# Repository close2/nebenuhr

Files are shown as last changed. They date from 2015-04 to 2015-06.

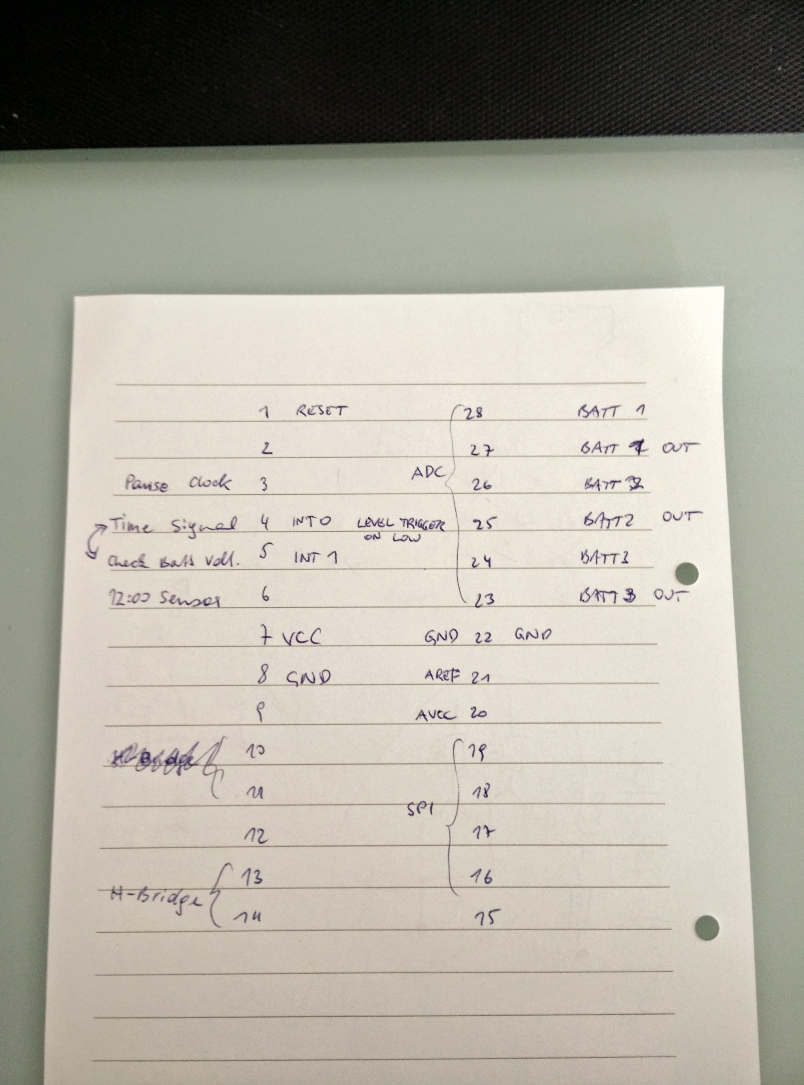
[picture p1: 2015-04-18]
doc/IMG_20150418_123037.jpg

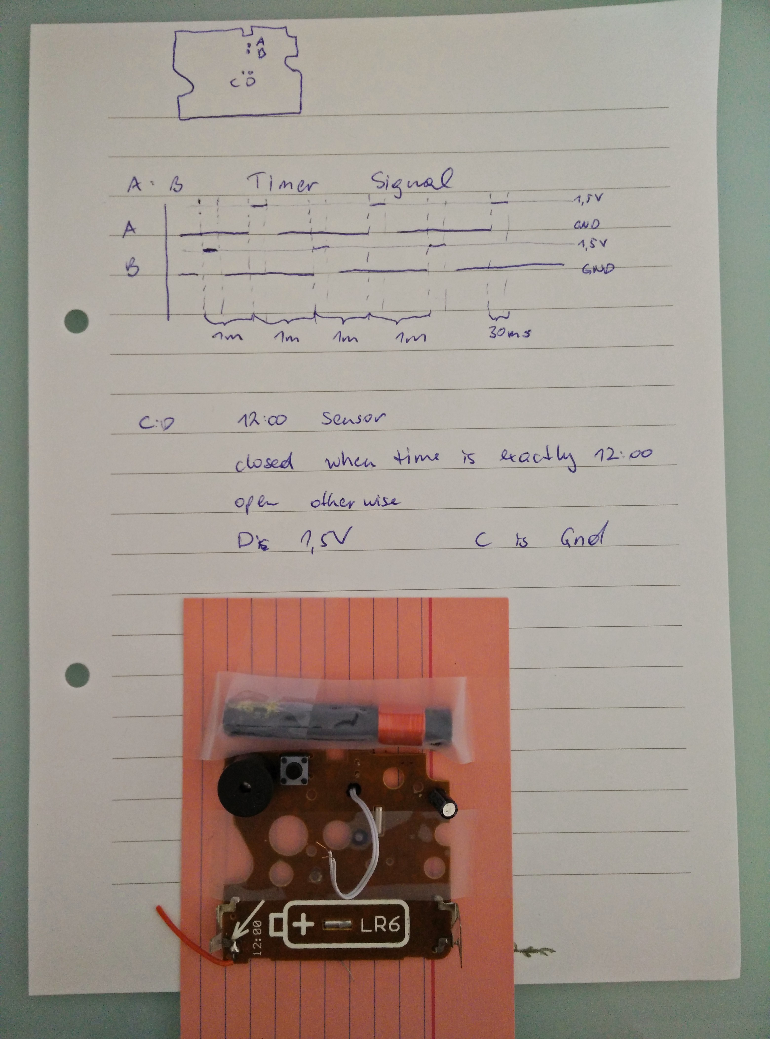
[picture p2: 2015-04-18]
doc/IMG_20150418_123128.jpg

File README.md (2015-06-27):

# nebenuhr
atmega code to control a secondary clock which would normally get its signal from a master clock.

## Idea

I reuse the board of a broken radio controlled clock.

See images in the doc directory.

The pins A and B of the clock powered a coil for a short amount of time (30ms) every minute.
As you can see in the diagram the polarity is reversed every minute.  (This is exactly the same
for the Nebenuhr.)  The signal on pins A and B are called timeSignal in my code.

When both arms (minute and hour) were at 12 o'clock Pin D was connected to ground (Pin C).

In my code I call this the noonSensor.  This was originally done with a light-sensor and 2 holes
in the hour/minute arms.

An Atmega is connected to the 3 (A, B and D) relevant pins of this board.

## Atmega

In order to use as little power as possible we power down the Atmega between timerSignals.

Only a low can wake an atmega when powered off,

                           VCC
                            |
                            1MΩ
                            |
                            ----------- Atmega TimeSignal Pin (INT1)
                            /
     Pin A -- 1MΩ -- Base |<
                            ↘
                             |
                            GND

And again the same for B.  Note that both A and B finally connect to the same Atmega pin.
(One resistor to VCC would be enough).

When A goes high (1.5V) the transistor pulls the Atmega pin to ground, waking the Atmega.

I considered connecting Pin D directly to the atmega and switching between HiZ and low,
but decided to play it safe.  A Mosfet connects Pin D to ground, when an Atmega pin
goes high:

    Pin D --
           |
           | Drain
           |
           Mosfet  Gate ---- 1kΩ ----- Atmega NoonSignal Pin
           |
           | Source
           |
          GND

An HBridge will power the coils of the nebenuhr.

                                 VCC
                                  |
                                  1MΩ
                                  |
       to P Channel left side  ----
                                   \
                                    >| 1kΩ -- Atmega HBridge1 Pin
                                   ↙        |
                                  |         |
                                 500kΩ     1kΩ
                                  |         |
                                 GND        to N Channel right side

Similar for P Channel right side, N Channel left side and HBridge2 Pin.

## Pause pin

Because the clock is pretty loud, setting a pin high disables the h-bridge output.
The atmega keeps count of the missed minute-arm movements and outputs them when the pin is set
low again.

The pin is simply either connected to VCC or GND:

              VCC
               |
                \
    
                     -- 1MΩ -- Atmega Pause Pin
    
                /
               |
              GND

## Battery check

As we have 3 power sources now:
* 1 AA battery for the old rc clock
* 1 battery (4.5V?) for the atmega
* 3 4.5V in series for the H-Bridge

i wanted to make it easy for the owner of the clock to find out, why the clock stopped working.
Pushing a button (INT0) will compare those voltages (or rather the divided voltages) to 1.1V and
turn on corresponding LEDs if the voltage seems high enough.

This was by far the most work.  *Don't do it.*

Either really remove the code, or connect 1MΩ to VCC on the check battery pin.

The difficulties:

- the voltage divider for the voltages should only be powered when the button is pressed.  
  I added Mosfets to only connect the voltage dividers to ground during measurements.
- the HBridge/ Nebenuhr voltage is to high for the atmega → simply not connecting to GND
  would result in 15+V to one of the atmega pins.  I finally simply added an solid state
  relay.
- Pressing the check battery button should wake the atmega and the button therefore connects
  the atmega pin to GND when pressed.  
  This means that I can not use the button to power the voltage divider. To measure the
  atmega voltage I used another pin to power the atmega voltage divider.

## libcl

This project uses my still incomplete libcl library.
Hopefully I will complete this libary soon and remove the header files from this project.
(And reference my libcl repository instead).

# Usage

- Power the atmega 4.5V
- Power the Nebenuhr ~15V
- move the Nebenuhr arms to 2 minutes before 12:00
- Power the rc-clock.

The rc-clock will now send 2 timer signals until the atmega sends the noon-signal.

Then the rc-clock will wait for an rc-signal.  In my case this could take several hours.

# Feel free to contact me.

I have the impression that writing this documentation costs me far more time than simply
answering questions... :(

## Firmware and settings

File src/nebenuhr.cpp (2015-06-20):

#define F_CPU 1000000UL

#include <avr/sleep.h>
#include "macros.h"
#include "tasks.h"
#include "clock.h"
#include "irqs.h"
#include "adc.h"


// wait timeSignalWaitPeriod ms until timeSignal is no longer present
// before turning IRQ for timeSignal on again.
const uint16_t timeSignalWaitPeriod = 10;

// when displayed time is not time, we move the minute finger faster
// but we will wait this pause (in ms) between every finger movement.
const uint16_t pauseBetweenHBridgePulses = 250;


template <typename T>
constexpr uint8_t voltsToUnits(T volts) {
  return 256 * volts / 1.1;
}

// 256 * minBatt1Voltage / 1.1 (1.1 ref voltage)
const auto batt1Min = voltsToUnits(0.8); // should be 186 units
const auto batt2Min = voltsToUnits(0.6);
const auto batt3Min = voltsToUnits(0.8); // should be 186 units


typedef PIN_DIP_3 PauseClockPin;

// DIP_4 is INT1 irq
typedef PIN_DIP_4 CheckBatteryVoltagePin;

// DIP_5 is INT0 irq
typedef PIN_DIP_5 TimeSignalPin;

typedef PIN_DIP_6 NoonSensorPin;


typedef PIN_DIP_13 HBridge1;
typedef PIN_DIP_14 HBridge2;

typedef PIN_DIP_11 VoltageFetPin;
typedef PIN_DIP_28 Batt1Pin;
typedef PIN_DIP_27 Batt1OutPin;
typedef PIN_DIP_26 Batt2Pin;
typedef PIN_DIP_25 Batt2OutPin;
typedef PIN_DIP_24 Batt3Pin;
typedef PIN_DIP_23 Batt3OutPin;


// using jumpers on the following pins let the user switch between different
// timings
typedef PIN_DIP_15 DurationIn0;
typedef PIN_DIP_16 DurationIn1;
typedef PIN_DIP_17 DurationIn2;
typedef PIN_DIP_18 DurationIn3;
typedef PIN_DIP_19 DurationIn4;

const uint16_t durations[32] = {
  ms_to_units((uint16_t) 130), // 0
  ms_to_units((uint16_t) 140),
  ms_to_units((uint16_t) 150),
  ms_to_units((uint16_t) 160),
  ms_to_units((uint16_t) 170),
  ms_to_units((uint16_t) 180),
  ms_to_units((uint16_t) 190),
  ms_to_units((uint16_t) 200),
  ms_to_units((uint16_t) 210),
  ms_to_units((uint16_t) 220),
  ms_to_units((uint16_t) 230), // 10
  ms_to_units((uint16_t) 240),
  ms_to_units((uint16_t) 250),
  ms_to_units((uint16_t) 260),
  ms_to_units((uint16_t) 270),
  ms_to_units((uint16_t) 280),
  ms_to_units((uint16_t) 290),
  ms_to_units((uint16_t) 300),
  ms_to_units((uint16_t) 320),
  ms_to_units((uint16_t) 340),
  ms_to_units((uint16_t) 360), // 20
  ms_to_units((uint16_t) 380),
  ms_to_units((uint16_t) 400),
  ms_to_units((uint16_t) 420),
  ms_to_units((uint16_t) 440),
  ms_to_units((uint16_t) 460),
  ms_to_units((uint16_t) 480),
  ms_to_units((uint16_t) 500),
  ms_to_units((uint16_t) 525),
  ms_to_units((uint16_t) 550),
  ms_to_units((uint16_t) 600), // 30
  ms_to_units((uint16_t) 650)
};

uint16_t time; // in minutes from 12:00; wraps every 12*60 minutes

// we allow the displayed time to be pause (for instance during the night,
// because the clock is really loud)
uint16_t displayedTime; // in minutes from 12:00; wraps every 12*60 minutes


///////////////////////////////  Task managment  ///////////////////////////////

enum Task {
  IncMinute = 0,
  CheckBatteries = 1,
  ReenableTimerSignalIrq = 2
};

uint8_t tasksToRun;


void startTask(Task task) {
  tasksToRun |= _BV(task);
}

void stopTask(Task task) {
  tasksToRun &= ~(_BV(task));
}

void stopAllTasks() {
  tasksToRun = 0;
}
  
uint8_t isAllTasksStopped() {
  return tasksToRun == 0;
}

uint8_t isTaskStarted(Task task) {
  return tasksToRun & _BV(task);
}
////////////////////////////////////////////////////////////////////////////////


////////////////////  NoonSensor -- related functionality  /////////////////////

void setNoonSensor(uint8_t v) {
  SET_BIT(NoonSensorPin, PORT, v);
}

void initNoonSensor() {
  SET_BIT(NoonSensorPin, DDR, 1);
  // do not automatically start with noon sensor on
}
////////////////////////////////////////////////////////////////////////////////


/////////////////  TimerSignal -- INT1 related functionality  //////////////////

void enableTimerSignalIRQ() {
  EIMSK |= _BV(INT1);
}

void disableTimerSignalIRQ() {
  EIMSK &= ~(_BV(INT1));
}

void initTimerSignal() {
  // nothing to do for pin
  // pins are Hi-Z input by default
  
  // turn on irq
  enableTimerSignalIRQ();
  sei();
}

#define NEW_IRQ_TASK IncMinuteIrqTask
IRQ_TASK(NEW_IRQ_TASK) {
  time++;
  if (time == 12 * 60) {
    time = 0;
    setNoonSensor(1);
  }
  else setNoonSensor(0);
        

  startTask(Task::IncMinute);
  startTask(Task::ReenableTimerSignalIrq);
  
  // turn off IRQ until signal from real clock is no longer present
  // otherwise this IRQ will trigger too often.
  disableTimerSignalIRQ();
};
#include "internal/register_irq_task_INT1.h"

uint8_t timerSignalPresent() {
  return GET_BIT(TimeSignalPin, PIN) == 0;
}

#define NEW_TASK ReenableTimerSignalIrqTask
struct NEW_TASK {
  static inline uint8_t is_enabled() {
    return isTaskStarted(Task::ReenableTimerSignalIrq);
  }
  
  template<typename T>
  static inline T run(const T& clock) {
    // we have to make sure the timeSignal is no longer present, before
    // turning irq for timeSignal on again.
    if (!timerSignalPresent()) {
      stopTask(Task::ReenableTimerSignalIrq);
      enableTimerSignalIRQ();
      return 0;
    }
    return ms_to_units(timeSignalWaitPeriod);
  }
};
#include REGISTER_TASK
////////////////////////////////////////////////////////////////////////////////


/////////////////  CheckBattery -- INT0 related functionality  /////////////////

void enableCheckBatteryIRQ() {
  EIMSK |= _BV(INT0);
}

void disableCheckBatteryIRQ() {
  EIMSK &= ~(_BV(INT0));
}

void initCheckBatteryPin() {
  // nothing to do for input pin
  // pins are Hi-Z input by default
  
  // turn output pins to output:
  SET_BIT(Batt1OutPin, DDR, 1);
  SET_BIT(Batt2OutPin, DDR, 1);
  SET_BIT(Batt3OutPin, DDR, 1);
  
  SET_BIT(VoltageFetPin, DDR, 1);
  
  // turn on irq
  enableCheckBatteryIRQ();
  sei();
}

#define NEW_IRQ_TASK CheckBatteryIrqTask
IRQ_TASK(NEW_IRQ_TASK) {
  startTask(Task::CheckBatteries);
  
  // turn off IRQ until button is no longer pressed
  // otherwise this IRQ will trigger too often.
  disableCheckBatteryIRQ();
};
#include "internal/register_irq_task_INT0.h"

uint8_t checkBatteryPressed() {
  return GET_BIT(CheckBatteryVoltagePin, PIN) == 0;
}
////////////////////////////////////////////////////////////////////////////////


////////////////////  PauseClock -- related functionality  /////////////////////

void initClockPaused() {
  // nothing to do
  // pins are Hi-Z input by default
}

uint8_t clockPaused() {
  return GET_BIT(PauseClockPin, PIN);
}
////////////////////////////////////////////////////////////////////////////////



///////////////  HBridgeOutDuration -- related functionality  //////////////////

void initHBridge() {
  SET_BIT(HBridge1, DDR, 1);
  SET_BIT(HBridge2, DDR, 1);
}

uint16_t readHBridgeOutDuration_units() {
  uint8_t index;
  // pins are by default input
  index = GET8_BYTE(PIN, 0, PIN_UNUSED, PIN_UNUSED, PIN_UNUSED, DurationIn4, DurationIn3, DurationIn2, DurationIn1, DurationIn0);
  
  return durations[index];
}
////////////////////////////////////////////////////////////////////////////////


#define NEW_TASK IncMinuteTask
struct NEW_TASK {
  static inline uint8_t is_enabled() {
    return isTaskStarted(Task::IncMinute);
  }
  
  template<typename T>
  static inline T run(const T& clock) {
    // this task will be called twice for every minute increment.
    // first to turn the output on and second to turn it off again.
    
    // we also need to keep track if we have to send a positive or negative
    // signal.
    
    enum HBridgeState {
      On = 0,
      OffPause = 1,
      Off = 2
    };
    
    static HBridgeState hBridgeState = Off;
    
    const uint8_t clockP = clockPaused();
    
    const uint8_t bridgeSelector = displayedTime & 0b1;
    
    if (hBridgeState == Off) {
      
      hBridgeState = On;
      if (!clockP) {
        if (bridgeSelector == 0) SET_BIT(HBridge1, PORT, 1);
        else SET_BIT(HBridge2, PORT, 1);

        displayedTime++;
        if (displayedTime == 12 * 60) displayedTime = 0;
      }
      
      // sleep for hbridgeOutDuration
      return readHBridgeOutDuration_units();
    } else if (hBridgeState == On) {
      
      hBridgeState = OffPause;
    
      // state is on → turn off
      SET_BIT(HBridge1, PORT, 0);
      SET_BIT(HBridge2, PORT, 0);
      
      return ms_to_units(pauseBetweenHBridgePulses);
    } else { // HBridgeState == OffPause
      
      hBridgeState = Off;
      
      if (clockP || displayedTime == time) {
        // mark IncMinuteTask as done:
        //             disable task in tasktracker
        stopTask(Task::IncMinute);
      }
    
      return 0;
    }
  }
};
#include REGISTER_TASK


#define NEW_TASK CheckBatteriesTask
struct NEW_TASK {
  static inline uint8_t is_enabled() {
    return isTaskStarted(Task::CheckBatteries);
  }
  
  typedef Adc<_adc::Mode::SingleConversion, _adc::Ref::V1_1, Batt1Pin> Adc_Batt1;
  typedef Adc<_adc::Mode::SingleConversion, _adc::Ref::V1_1, Batt2Pin> Adc_Batt2;
  typedef Adc<_adc::Mode::SingleConversion, _adc::Ref::V1_1, Batt3Pin> Adc_Batt3;
  
  template<typename T>
  static inline T run(const T& clock) {
    // "turn on" fet to pass voltages from batteries:
    SET_BIT(VoltageFetPin, PORT, 1);
    
    Adc_Batt1::init();
    const uint8_t batt1 = Adc_Batt1::adc_8bit();
    // don't need to turn off adc
    
    Adc_Batt2::init();
    const uint8_t batt2 = Adc_Batt2::adc_8bit();
    // don't need to turn off adc
    
    Adc_Batt3::init();
    const uint8_t batt3 = Adc_Batt3::adc_8bit();
    
    SET_BIT(Batt1OutPin, PORT, (batt1 > batt1Min));
    SET_BIT(Batt2OutPin, PORT, (batt2 > batt2Min));
    SET_BIT(Batt3OutPin, PORT, (batt3 > batt3Min));
    
    if (checkBatteryPressed()) return ms_to_units(200);
    
    // user no longer presses battery check button
    
    Adc_Batt3::turn_off();
    SET_BIT(VoltageFetPin, PORT, 0);
    
    // turn off all outputs:
    SET_BIT(Batt1OutPin, PORT, 0);
    SET_BIT(Batt2OutPin, PORT, 0);
    SET_BIT(Batt3OutPin, PORT, 0);
    
    stopTask(Task::CheckBatteries);
    
    enableCheckBatteryIRQ();
    
    return 0;
  }
};
#include REGISTER_TASK

//#define TEST7

#ifdef TEST1
  // test led output
  __attribute__ ((OS_main)) int main(void) {
    
    SET_BIT(Batt1OutPin, DDR, 1);
    SET_BIT(Batt2OutPin, DDR, 1);
    SET_BIT(Batt3OutPin, DDR, 1);
    
    SET_BIT(Batt1OutPin, PORT, 1);
    SET_BIT(Batt2OutPin, PORT, 1);
    SET_BIT(Batt3OutPin, PORT, 1);
    for (;;);
    return 0;
  }
#  define USE_ONLY_DEFINED_IRQS
#  include REGISTER_IRQS

#elif defined TEST2

  // test power down
  __attribute__ ((OS_main)) int main(void) {
    
    set_sleep_mode(SLEEP_MODE_PWR_DOWN);
    
    for (;;) {
      cli();
      sleep_enable();
      sei();
      sleep_enable();
      sleep_cpu();
      
      // visual indicator if sleep isn't entered:
      SET_BIT(Batt1OutPin, DDR, 1);
      SET_BIT(Batt1OutPin, PIN, 1);
    }
    return 0;
  }
#  define USE_ONLY_DEFINED_IRQS
#  include REGISTER_IRQS

#elif defined TEST3
#  include <util/delay.h>

  // test hbridge
  __attribute__ ((OS_main)) int main(void) {
    
    initHBridge();
    for (;;) {
      SET_BIT(HBridge1, PORT, 1);
      _delay_ms(2000);
      SET_BIT(HBridge1, PORT, 0);
      _delay_ms(2000);
      SET_BIT(HBridge2, PORT, 1);
      _delay_ms(2000);
      SET_BIT(HBridge2, PORT, 0);
      _delay_ms(2000);
    }
    return 0;
  }
#  define USE_ONLY_DEFINED_IRQS
#  include REGISTER_IRQS

#elif defined TEST4
  // test power output wenn hbridge is off
  __attribute__ ((OS_main)) int main(void) {
    
    initHBridge();
    SET_BIT(HBridge1, PORT, 0);
    SET_BIT(HBridge2, PORT, 0);
    for (;;);
    return 0;
  }
#  define USE_ONLY_DEFINED_IRQS
#  include REGISTER_IRQS

#elif defined TEST5

__attribute__ ((OS_main)) int main(void) {
  
  set_sleep_mode(SLEEP_MODE_PWR_DOWN);
  
  // start with all tasks stopped
  stopAllTasks();
  
  displayedTime = 0;
  time = 0x0FFF;
  tasksToRun |= Task::IncMinute;
  
  initNoonSensor();
  initClockPaused();
  initTimerSignal();
  initHBridge();
  initCheckBatteryPin();
  
  for (;;) {
    execTasks<uint16_t, TASK_LIST>();
    
    // if all tasks are done
    // power down
    // go to sleep without race conditions...
    cli();
    if (isAllTasksStopped()) {
      sleep_enable();
      sei();
      sleep_cpu();
      sleep_disable();
    }
    sei();
  }
  return 0;
}

#define USE_ONLY_DEFINED_IRQS
#include REGISTER_IRQS

#elif defined TEST6
__attribute__ ((OS_main)) int main(void) {
  
  set_sleep_mode(SLEEP_MODE_PWR_DOWN);
  
  // start with all tasks stopped
  stopAllTasks();
  
  displayedTime = 12 * 60 - 2;
  time = displayedTime;
  
  initNoonSensor();
  initClockPaused();
  initTimerSignal();
  initHBridge();
  initCheckBatteryPin();
  
  for (;;) {
    startTask(Task::CheckBatteries);
    execTasks<uint16_t, TASK_LIST>();
  }
  return 0;
}
#define USE_ONLY_DEFINED_IRQS
#include REGISTER_IRQS

#elif defined TEST7

__attribute__ ((OS_main)) int main(void) {
  
  set_sleep_mode(SLEEP_MODE_PWR_DOWN);
  
  // start with all tasks stopped
  stopAllTasks();
  
  displayedTime = 12 * 60 + 2;
  time = displayedTime;
  
  initNoonSensor();
  initClockPaused();
  initTimerSignal();
  initHBridge();
  initCheckBatteryPin();
  
  startTask(Task::IncMinute);
  for (;;) {
    execTasks<uint16_t, TASK_LIST>();
    
    // if all tasks are done
    // power down
    // go to sleep without race conditions...
    cli();
    if (isAllTasksStopped()) {
      sleep_enable();
      sei();
      sleep_cpu();
      sleep_disable();
    }
    sei();
  }
  return 0;
}

#define USE_ONLY_DEFINED_IRQS
#include REGISTER_IRQS

#else


__attribute__ ((OS_main)) int main(void) {
  
  set_sleep_mode(SLEEP_MODE_PWR_DOWN);
  
  // start with all tasks stopped
  stopAllTasks();
  
  displayedTime = 12 * 60 - 2;
  time = displayedTime;
  
  initNoonSensor();
  initClockPaused();
  initTimerSignal();
  initHBridge();
  initCheckBatteryPin();
  
  for (;;) {
    execTasks<uint16_t, TASK_LIST>();
    
    // if all tasks are done
    // power down
    // go to sleep without race conditions...
    cli();
    if (isAllTasksStopped()) {
      sleep_enable();
      sei();
      sleep_cpu();
      sleep_disable();
    }
    sei();
  }
  return 0;
}

#define USE_ONLY_DEFINED_IRQS
#include REGISTER_IRQS

#endif

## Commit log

2015-04-19 feat/fix: fix Task enum int value
    add separate task to reenable TimerSignalIrq
    add voltsToUnits
    [nebenuhr.cpp]
2015-04-26 fix: call initHBridgeOutDuration to read value from eeprom
    [nebenuhr.cpp]
2015-05-30 fix: use correct mcu; impr timings; fix isAllTasksStopped
    fix copy paste error HBridge enable (HBridge1 turned on instead of HBridge2)
    [nebenuhr.cpp]
2015-06-09 fix: use correct INT{0,1} for battery check / time signal
    [nebenuhr.cpp]
2015-06-12 fix: fix remaining mismatches of INT{0,1}; use displayedTime for hBridgeSelection
    we now use the displayedTime as selector for the hBridge{1,2}
    This fixes problems we had when the output was paused.
    [nebenuhr.cpp]
2015-06-12 fix: don't enable IRQ in hbridgeTask
    introduce OffPause state to really wait between hBridge outputs.
    [nebenuhr.cpp]
2015-06-12 fix: use correct bit mask
    :( embarassing bug
    [nebenuhr.cpp]
2015-06-13 feat: start 2 minutes before 12:00
    The rc clock didn't allow to start with the noon sensor closed.
    [nebenuhr.cpp]
2015-06-19 fix: make voltage measurement work; read hBridgeDuration every time
    set voltageFetPin to output
    call initCheckBatteryPin
    don't turn ADC unit off every round.
    (strange bug, where first read afterwords would always return
    last read before turning off)
    remove hBridgeOutDuration_units and read value from pins every time
    [nebenuhr.cpp]
2015-06-20 feat: reduce comparison voltage for 4.5V to 0.6V
    we have added an 1k resistor before the voltage divider.
    Reaching 0.8V wouldn't be possible if we wanted 3.8V as
    minimum supply voltage. (poti has only 220Ω)
2015-06-27 feat: improve readme, add Fritzing file
    Fritzing file is not complete, but should demonstrate some connections.
    [nebenuhr.fzz]
2015-06-27 fix: had not saved Fritzing
    [nebenuhr.fzz]
